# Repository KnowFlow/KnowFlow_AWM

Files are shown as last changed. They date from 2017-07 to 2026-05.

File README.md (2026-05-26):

This branch is for ongoing development

# KnowFlow - an open source river quality meter with Arduino

KnowFlow is an open source water monitoring device and an education program.



For the device part, KnowFlow is designed for environmental activists, researchers, students... anyone
who wants to know the water quality using low cost and customized tools. It is based on Arduino Uno and 
can currently monitor 5 parameters: Temperature, pH, ORP, Electrical conductivity and Dissolved Oxygen. 
The data is stored on a micro SD card and can be read directly on phone by bluetooth (except for Dissolved Oxygen). 
All the modules are easy to change or add. Most of the sensors used are from DFRobot and Atlas Scientific, 
the main 2 sensor suppliers for Arduino users.

### Supported Hardware Platforms
- **Arduino Uno** (primary platform)
- **Arduino Mega 2560**
- **Arduino M0**
- **ESP32** ✅ (see [ESP32 README](ArduinoESP32/README.md))



For the education program, KnowFlow is an 8 week online course and a learning group hosted on 
Greenseed Project platform. During the course, we cover the fundamentals of water quality, indicators of water quality, 
Arduino and monitoring systems and show you how to build your own monitoring system based on Arduino. In addition to 
the 5 included in the KnowFlow kits, you can add other environmental sensors, such as carbon dioxide, ozone, 
dust, light, temperature, or humidity sensors, then add GPS and a communication module to connect data from a distance. 
Step by step demos in the course walk you through the learning process.

This page is a collective information for KnowFlow, it can also be found on github, [Youku](http://v.youku.com/v_show/id_XMTYzNTA1NzU1Mg==.html?spm=a2hzp.8253876.0.0&f=27620513).
Will release this series video tutorial on youtube later soon!

## KnowFlow Hardware 

A complete list of components, measurements, drawings, and other specifications can be found [here](https://docs.google.com/spreadsheets/d/1rwVUIwqTOvZiKi_0vdBPrXMIw2YB-nsFnhaVy5seE-M).
DFRobot also offers a [KnowFlow starter kit.](https://www.dfrobot.com/product-1649.html)

#### Central Control Unit: 
* Arduino Uno (DFRobot Bluno in this case) and 
* Expansion Shield (DFRobot Expansion Shield V7.1 in this case)  
* real time clock circuit board
#### Water Sensors: 
* pH (pH probe and pH circuit board)
* EC (EC probe and EC circuit board)
* ORP (ORP probe and ORP circuit board)
* Temperature (temperature probe and temperature circuit board)
* Dissolved Oxygen (DO probe, BNC and circuit board)
#### Analog conversion:
* DFRobot Gravity: I2C ADS1115 16-Bit ADC Module (DFR0553)
  * I2C address: `0x48` by default, or `0x49` when the module address switch is changed
  * Input range: `0~VCC`
  * Default channel mapping in firmware: `A0=EC`, `A1=pH`, `A2=ORP`, `A3=AUX`
#### Data Storage:
* Micro-SD module
* Micro SD card
#### Fit and finish:
* Mounting plate
* Water proof box(200mm_150mm_75mm)
* Water proof bushing
#### Other parts: 
* Wires
* Bread board
* Bolts and nuts
* Screws
* Battery
* Double-sided adhesive
* Write on tape
* Basic hand tools
* Spiral cable wrap 

## Installing KnowFlow Firmware
KnowFlow is designed for beginners. You don't need to have experience with Arduino or software development. 
KnowFlow is packaged with supporting software libraries to make it easier for you to enable different sensor features 
for your application. Feel free to post your software questions on our wiki page on public lab or github.

### Firmware Versions

This repository contains multiple firmware versions for different hardware configurations:

#### 1. ArduinoUnoDo
- **Location**: `ArduinoUnoDo/WaterMonitor/`
- **DO Sensor**: Uses Serial port communication (Rx(0), Tx(1))
- **Best for**: Atlas Scientific DO sensor or similar serial-based DO sensors
- **Note**: DO sensor uses Serial port, which may conflict with USB debugging

#### 2. ArduinoUnoGravityDo
- **Location**: `ArduinoUnoGravityDo/WaterMonitorDo/`
- **DO Sensor**: Uses analog pin A0 (Gravity DO sensor)
- **Best for**: DFRobot Gravity DO sensor
- **Features**: Includes calibration support for pH and EC sensors
- **Recommended**: This is the most feature-complete version

#### 3. ArduinoESP32
- **Location**: `ArduinoESP32/WaterMonitorESP32/`
- **DO Sensor**: Uses analog pin GPIO33 (Gravity DO sensor)
- **Best for**: ESP32 development boards
- **Features**: 
  - Uses ESP32's 12-bit ADC for higher precision
  - Compatible with all 5 sensors
  - Ready for WiFi/IOT features (planned)
- **Note**: Requires ESP32 board support in Arduino IDE

#### 4. Firmware (Legacy)
- **Location**: `Firmware/WaterMonitor/WaterMonitor/`
- **Status**: Legacy version, contains compiled binaries
- **Note**: Use for reference only

### Installation Steps

1. **Download Arduino IDE** (version 1.8.2 or later)
   - Download link: https://www.arduino.cc/en/Main/Software

2. **Download KnowFlow code**
   ```bash
   git clone https://github.com/KnowFlow/KnowFlow_AWM.git
   ```

3. **Choose the appropriate firmware version**
   - For **ESP32**: Use `ArduinoESP32/WaterMonitorESP32/` (see [ESP32 README](ArduinoESP32/README.md))
   - For **Gravity DO sensor** (Arduino Uno): Use `ArduinoUnoGravityDo/WaterMonitorDo/`
   - For **Serial DO sensor** (Arduino Uno): Use `ArduinoUnoDo/WaterMonitor/`

4. **Install required libraries**
   - Copy libraries from `Firmware/libraries/` to your Arduino IDE libraries folder
   - Or install OneWire library via Library Manager: Sketch → Include Library → Manage Libraries → Search "OneWire"

5. **Configure your hardware**
   - Edit `config.h` (or `Config.h`) to match your sensor pins and calibration values
   - Enable/disable debug output by uncommenting `DEBUG_AVR` or `DEBUG_M0`

6. **Upload to board**
   - Open `WaterMonitor.ino` (or `WaterMonitorDo.ino`) in Arduino IDE
   - Connect your Arduino Uno board
   - Select Tools → Board: Arduino Uno
   - Select Tools → Port: (your USB port)
   - Click "Verify" then "Upload"

### DFR0553 ADC configuration

The enhanced `ArduinoUnoDo/WaterMonitor` firmware supports the Gravity DFR0553 I2C 16-bit ADC module without requiring the external DFRobot ADS1115 library. Configure it in `ArduinoUnoDo/WaterMonitor/config.h`:

* `ENABLE_DFR0553_ADC`: enable or disable the I2C ADC path.
* `DFR0553_I2C_ADDRESS`: default `0x48`; set to `0x49` if the hardware address switch is changed.
* `DFR0553_FULL_SCALE_MV`: default `6144.0f`, matching the ADS1115 `+/-6.144V` full-scale setting used for `0~VCC` single-ended sensor inputs.
* `DFR0553_EC_CHANNEL`, `DFR0553_PH_CHANNEL`, `DFR0553_ORP_CHANNEL`: map the EC, pH, and ORP analog front ends to ADS1115 channels.

If the DFR0553 is not detected on I2C, the firmware falls back to the original MCU `analogRead()` path for the analog sensors.

## FAQ

### Q: Why can't I verify the code?
**A:** The IDE may be missing a library, most often OneWire. 
Install the missing library from Sketch → Include Library → Manage Libraries. Search "OneWire" then install it.

### Q: Which firmware version should I use?
**A:** 
- Use **ArduinoUnoGravityDo** if you have DFRobot Gravity DO sensor (recommended)
- Use **ArduinoUnoDo** if you have Atlas Scientific or other serial-based DO sensors
- Check your DO sensor documentation to determine which type you have

### Q: How do I calibrate the sensors?
**A:** 
- Edit `config.h` (or `Config.h`) in your firmware directory
- Set `PHOFFSET` for pH calibration offset
- Set `ECKVALUE` for EC sensor K value
- Re-upload the firmware after calibration

### Q: Can I use both Serial DO and Gravity DO?
**A:** No, you need to choose one firmware version based on your hardware. The two versions are incompatible due to different DO sensor interfaces.

### Q: How do I enable debug output?
**A:** 
- Open `config.h` (or `Config.h`)
- Uncomment `#define DEBUG_AVR` for Arduino Uno/Mega
- Or uncomment `#define DEBUG_M0` for Arduino M0
- Re-upload the firmware

## How to build KnowFlow 
Instructions are available [here.](https://publiclab.org/notes/shanlter/06-08-2017/knowflow-automatic-water-meter)

## How to contribute:
See this [tutorial.](https://help.github.com/articles/creating-a-pull-request/)
1. Fork the repository!
1. Create your feature branch: git checkout -b my-new-feature
1. Commit your changes: git commit -am 'Add some feature'
1. Push to the branch: git push origin my-new-feature
1. Submit a pull request
 
## About Branches
**master** is the current stable release.

**development** is the research version. It has experimental features that are not fully tested. For example, IOT
integrations, new sensors, etc.

**test** is for the team to practice with github. We will delete when we figure out how to use github. (We are newbees
to github, so please forgive any stupid errors. Suggestions are welcome!) :)

## To DO List
- [x] Support DO Sensor from DFRobot
- [x] Modify the construction of the files system
- [x] Code cleanup and configuration unification
- [x] Add DFR0553 I2C 16-bit ADC support for ArduinoUnoDo analog sensors
- [ ] Add YouTube video tutorial
- [ ] Website setup (www.knowflow.org)
- [x] IOT feature for enhanced ArduinoUnoDo firmware
- [x] Calibration function (partially implemented in ArduinoUnoGravityDo)
- [x] ESP32 support (basic sensor functionality)
- [ ] ESP32 WiFi/IOT features
- [x] Low power function for enhanced ArduinoUnoDo firmware

## Contact

Email addresses for the KnowFlow team.

* Rockets <Rockets.xia@dfrobot.com>
* He Shan  <shanh0510@gmail.com>
* Lauren <Lauren.pan@hotmail.com>
* Jason <jason.liang@dfrobot.com>

## Documents

 * [Tutorial][1]
 * [GreenSeed online courses][2]
 * [Application:非洲茶园水质调研][3]
 * [Application:Willow Creek Water Quality Monitoring][4]
 * [KnowFlow Special Design][6]

## License

All KnowFlow related materials are released under the [Attribution-NonCommercial-ShareAlike 4.0 International (CC BY-NC-SA 4.0)][5]

## This project has benefited from the support from the following funders:

* GreenSeed Foundation
* Mushroom Cloud Maker Space

  [1]: https://publiclab.org/notes/shanlter/06-08-2017/knowflow-automatic-water-meter
  [2]: http://blog.sina.com.cn/s/blog_9f86b6d50102w9m1.html
  [3]: http://www.dfrobot.com.cn/community/thread-26733-1-1.html
  [4]: https://publiclab.org/notes/MadTinker/07-31-2017/willow-creek-water-quality-monitoring
  [5]: https://creativecommons.org/licenses/by-nc-sa/4.0/
  [6]:https://www.instructables.com/id/KnowFlow-Special-Design/

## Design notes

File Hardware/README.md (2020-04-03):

## Diagrams
Box_and_Plate diagrams are provided by KnowFlow team.
Box_and_Plate_v2 is update.
It's have more posion to put the board and easy to install.

Knowflow board diagrams are provided by a community member. These diagrams were created in 
[Sketchup](https://www.sketchup.com/) and can be edited with free software. They offer an alternative mounting
layout for [this box.](http://cgi.ebay.com/ws/eBayISAPI.dll?ViewItemVersion&item=112434164913&view=all&tid=1783224276001)
Drawings will print 1:1 so the printout can be used as a template to drill holes. Consider 
[this item](https://www.dollartree.com/Home-Collection-Paddle-Cutting-Boards/p338120/index.pro) 
as a mounting plate.

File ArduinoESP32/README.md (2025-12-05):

# KnowFlow ESP32 版本

这是 KnowFlow 水质监测系统的 ESP32 移植版本，支持 ESP32 开发板运行原有的 5 个传感器（pH, Temperature, DO, EC, ORP）。

## 特性

- ✅ 支持所有 5 个传感器（pH, Temperature, DO, EC, ORP）
- ✅ 利用 ESP32 的 12-bit ADC 获得更高精度
- ✅ 兼容现有的传感器驱动代码
- ✅ 支持 SD 卡数据存储
- ✅ 支持 RTC 时间记录
- 🔜 WiFi 数据上传（计划中）
- 🔜 蓝牙配置（计划中）

## 硬件要求

### 开发板
- ESP32 开发板（推荐 ESP32-DevKitC）
- 支持 Arduino IDE 的 ESP32 开发环境

### 传感器
- pH 传感器（DFRobot Gravity pH Sensor）
- EC 传感器（DFRobot Gravity EC Sensor）
- ORP 传感器（DFRobot Gravity ORP Sensor）
- DO 传感器（DFRobot Gravity DO Sensor）
- 温度传感器（DS18B20）

### 其他
- Micro SD 卡模块（SPI 接口）
- RTC 模块（I2C 接口，可选，可使用 NTP）

## 引脚配置

### 传感器引脚（ESP32 GPIO）
- **pH**: GPIO34 (ADC1_CH6)
- **EC**: GPIO35 (ADC1_CH7)
- **ORP**: GPIO32 (ADC1_CH4)
- **DO**: GPIO33 (ADC1_CH5)
- **Temperature**: GPIO4 (OneWire)

### SD 卡引脚（SPI）
- **MOSI**: GPIO23
- **MISO**: GPIO19
- **CLK**: GPIO18
- **CS**: GPIO5

### I2C 引脚（RTC）
- **SDA**: GPIO21
- **SCL**: GPIO22

## 安装步骤

### 1. 安装 Arduino IDE 和 ESP32 支持

1. 下载并安装 [Arduino IDE](https://www.arduino.cc/en/software)（1.8.13 或更高版本）

2. 添加 ESP32 开发板支持：
   - 打开 Arduino IDE
   - 文件 → 首选项
   - 在"附加开发板管理器网址"中添加：
     ```
     https://raw.githubusercontent.com/espressif/arduino-esp32/gh-pages/package_esp32_index.json
     ```
   - 工具 → 开发板 → 开发板管理器
   - 搜索 "ESP32" 并安装

### 2. 安装必要的库

从 `Firmware/libraries/` 目录复制以下库到 Arduino IDE 的 libraries 文件夹：
- OneWire
- Wire（ESP32 已内置，但可能需要）

或者通过库管理器安装：
- OneWire（搜索 "OneWire"）

### 3. 配置项目

1. 打开 `WaterMonitorESP32.ino`
2. 编辑 `Config.h` 调整以下配置：
   - 传感器校准值（`PHOFFSET`, `ECKVALUE`）
   - 调试输出（`DEBUG_ESP32`）
   - 引脚配置（如果需要修改）

### 4. 上传代码

1. 连接 ESP32 开发板到电脑
2. 选择开发板：工具 → 开发板 → ESP32 Arduino → ESP32 Dev Module
3. 选择端口：工具 → 端口 → （你的 ESP32 端口）
4. 点击"上传"

## ADC 精度说明

ESP32 使用 12-bit ADC（0-4095），比 Arduino 的 10-bit ADC（0-1023）精度更高。代码中包含了适配层，可以将 ESP32 的 ADC 值转换为 Arduino 兼容的值，同时也可以直接使用 ESP32 的更高精度。

### 使用 Arduino 兼容模式（默认）
传感器驱动会自动将 ESP32 的 12-bit 值转换为 10-bit 值，保持与 Arduino 版本的兼容性。

### 使用 ESP32 高精度模式
如果需要更高的精度，可以修改传感器驱动代码，直接使用 ESP32 的 12-bit ADC 值。

## 电压兼容性

### 传感器输出
- DFRobot Gravity 传感器通常输出 0-3.3V 信号，兼容 ESP32 的 3.3V 逻辑电平
- 传感器模块可能需要 5V 供电，但输出信号是 3.3V 兼容的

### 注意事项
- 如果传感器需要 5V 供电，确保 ESP32 开发板有 5V 输出引脚，或使用外部 5V 电源
- 不要将 5V 信号直接连接到 ESP32 GPIO（会损坏芯片）
- 如果传感器输出超过 3.3V，需要使用电平转换电路

## 故障排除

### 问题：编译错误
- 确保已安装 ESP32 开发板支持
- 确保所有必要的库都已安装
- 检查 Arduino IDE 版本（需要 1.8.13+）

### 问题：传感器读数不准确
- 检查引脚配置是否正确
- 检查传感器供电是否正常
- 检查 ADC 配置（`initESP32ADC()` 函数）
- 可能需要重新校准传感器

### 问题：SD 卡无法识别
- 检查 SPI 引脚连接
- 检查 SD 卡格式（建议使用 FAT32）
- 检查 CS 引脚配置

## 未来计划

- [ ] WiFi 数据上传功能
- [ ] 蓝牙配置功能
- [ ] NTP 时间同步
- [ ] OTA 固件更新
- [ ] Web 配置界面
- [ ] 低功耗模式

## 贡献

欢迎提交 Issue 和 Pull Request！

## 许可证

与主项目相同：GNU General Public License v3.0

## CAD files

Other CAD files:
Hardware/Box_and_Plate_v2.dwg
Hardware/Box_and_Plate.dwg

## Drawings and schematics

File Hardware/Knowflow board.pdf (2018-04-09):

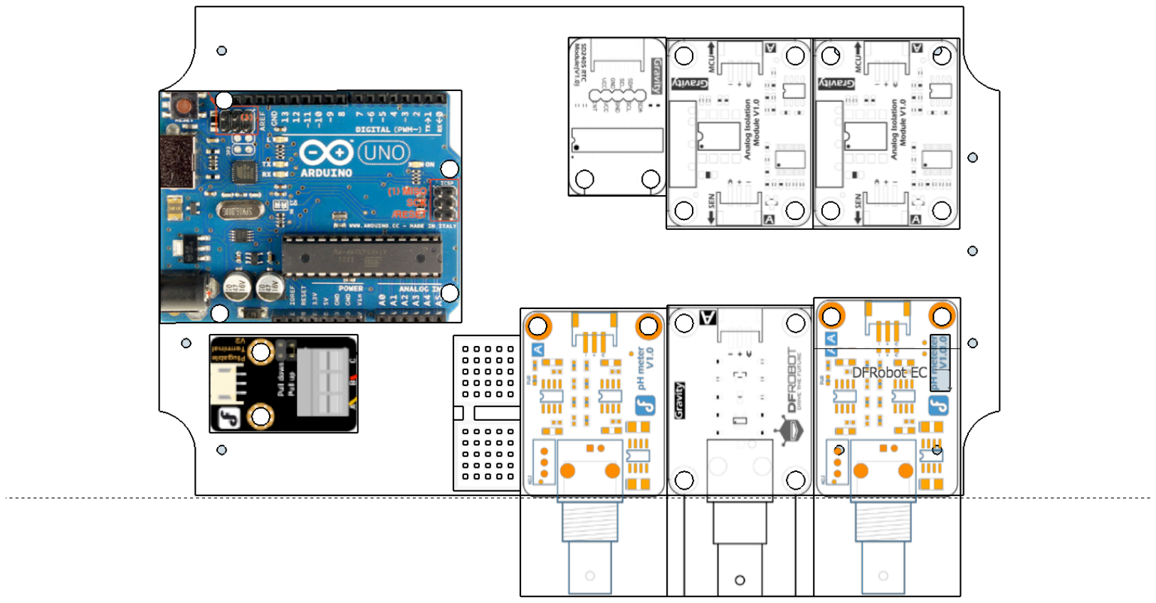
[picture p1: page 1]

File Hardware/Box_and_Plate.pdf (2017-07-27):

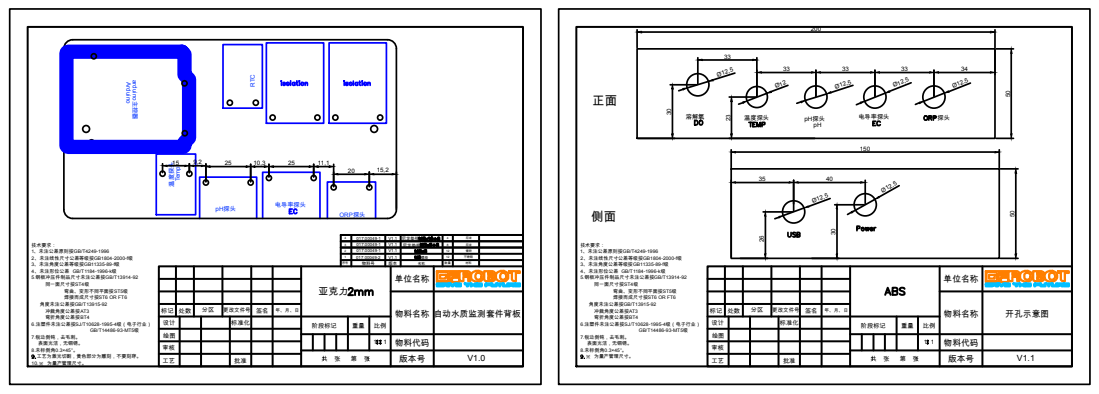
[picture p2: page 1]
4、未注形位公差 GB/T1184-1996-k级; 焊接而成尺寸按ST6 OR FT6; ※ 为量产管理尺寸。; 10.※ 为量产管理尺寸。

4 017.00049-1 | V1.1 | 尼龙垫柱 | 4 尼龙
3 017.00049-1 2/1 017.00049-1 | V1.1 | 尼龙垫柱 | 8 尼龙 12 镀锌

017.00049-2 | V1.1 | 螺母 | 12 不锈钢

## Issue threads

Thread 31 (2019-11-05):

We will have a NB-IoT version of KnowFlow

rockets-cn, 2019-11-05:
We are going to rebuild KnowFlow base on a new board that is using the NB-IoT system.
hope that we can release demo in a few weeks.

thegspdman, 2020-03-22:
Hi there;
I bought the knowFlow kit from DFrobot for a project for my thesis and now I am trying to verify/upload the code to the Bluno but i am having all sorts of fault messages. I am not god with coding, unfortunately my field is water and wastewater. Would you be kind enough and email me a working code or put me towards the right direction please. IoT project sounds brilliant.
Kind regards
Zak

rockets-cn, 2020-03-25:
How can I help?

thegspdman, 2020-03-25:
Hi there;
Very happy to hear from you.
I am a environment and water/wastewater student.I bought a water monitoring
kit " excluding ORP sensor" from DFrobot, but I am having problems with the
program/equipment.
1- The Bluno can't be detected by my Dell XPS with windows 10
2- I got all kind of errors verifying the program, like program is too big,
stray errors ...and so forth.
3- I have a Mega from Keyestudio that can be recognized by my PC, I could
verify but unfortunately it doesn't upload to board.
I would love to use the Bluno and the rest of the kit if it only works.
Can you help please, I am trying to do it as a project for my thesis to
raise awareness about IOT to be introduced for water and wastewater
treatment plants.
Kind regards
Ishak

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

--
Ishak Fernini
Tåsjö 230
Hoting -Jämtland-
Sverige
Tel: +44 72 532 0631
thegspdman@gmail.com

rockets-cn, 2020-04-03:
I think maybe you have to install the driver for the Bluno.
maybe we can use zoom or another way contact directly.

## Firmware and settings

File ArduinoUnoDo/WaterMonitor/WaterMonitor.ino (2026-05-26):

/*********************************************************************
 * WaterMonitor.ino - Enhanced KnowFlow with IoT, Calibration, and Power Management
 *
 * Copyright (C)    2024   KnowFlow Team
 * Enhanced version with WiFi/IoT connectivity, calibration, and power management
 *
 * Description:
 * Enhanced water quality monitoring system with:
 * - WiFi/IoT connectivity via MQTT
 * - Automatic sensor calibration
 * - Power management with sleep modes
 * - Battery monitoring and solar charging support
 * - Real-time data transmission
 *
 * Hardware platform   : Arduino Uno with WiFi shield or ESP32
 * New features added  : IoT connectivity, calibration, power management
 * version :  V2.0
 * date    :  2024-07-21
 **********************************************************************/

#include <SPI.h>
#include <SD.h>
#include <Wire.h>
#include <EEPROM.h>
#include "config.h"

// Core modules
#include "GravitySensorHub.h"
#include "GravityRtc.h"
#include "SdService.h"
#include "Debug.h"

// New enhanced features
#include "IoTService.h"
#include "CalibrationService.h"
#include "PowerManager.h"

// Clock module
GravityRtc rtc;

// Sensor monitoring
GravitySensorHub sensorHub;
SdService sdService = SdService(sensorHub.sensors);

// New services
IoTService iotService;
CalibrationService calibrationService(&sensorHub, &sdService);
PowerManager powerManager;

// System state
unsigned long lastUpdateTime = 0;
unsigned long updateInterval = 5000; // 5 seconds between readings
bool systemInitialized = false;

void setup() {
    Serial.begin(DEBUG_BAUD_RATE);
    Serial.println(F("KnowFlow Enhanced Water Monitor v2.0"));
    Serial.println(F("====================================="));

    // Initialize EEPROM for calibration data
    EEPROM.begin(512);

    // Initialize RTC
    rtc.setup();

    // Initialize sensor hub
    sensorHub.setup();

    // Initialize SD service
    sdService.setup();

    // Initialize calibration service
    calibrationService.setup();

    // Initialize power manager
    PowerConfig powerConfig;
    powerConfig.sleepInterval = POWER_SLEEP_INTERVAL;
    powerConfig.lowBatteryThreshold = LOW_BATTERY_THRESHOLD;
    powerConfig.criticalBatteryThreshold = CRITICAL_BATTERY_THRESHOLD;
    powerConfig.enableBatteryMonitoring = ENABLE_BATTERY_MONITORING;
    powerConfig.enableSensorPowerControl = ENABLE_SENSOR_POWER_CONTROL;
    powerConfig.enableSolarCharging = ENABLE_SOLAR_CHARGING;

    powerManager.setup(powerConfig);

    // Initialize IoT service (WiFi/MQTT)
    Serial.print(F("Initializing IoT service..."));
    iotService.setup(WIFI_SSID, WIFI_PASSWORD, MQTT_SERVER, MQTT_PORT);
    Serial.println(F("OK"));

    systemInitialized = true;
    Serial.println(F("System initialization complete!"));
    Serial.println(F("====================================="));
}

void loop() {
    if (!systemInitialized) return;

    unsigned long currentTime = millis();

    // Update all services
    rtc.update();
    sensorHub.update();
    sdService.update();
    calibrationService.loop();
    powerManager.loop();
    iotService.loop();

    // Main update cycle
    if (currentTime - lastUpdateTime > updateInterval) {
        lastUpdateTime = currentTime;

        // Get all sensor readings
        float ph = sensorHub.getValueBySensorNumber(0);
        float temp = sensorHub.getValueBySensorNumber(1);
        float doValue = sensorHub.getValueBySensorNumber(2);
        float ec = sensorHub.getValueBySensorNumber(3);
        float orp = sensorHub.getValueBySensorNumber(4);

        // Print readings
        printSensorReadings(ph, temp, doValue, ec, orp);

        // Publish to IoT
        if (iotService.isConnected()) {
            iotService.publishData(ph, temp, doValue, ec, orp);
        }

        // Check for calibration commands
        handleSerialCommands();
    }
}

void printSensorReadings(float ph, float temp, float doValue, float ec, float orp) {
    Serial.println(F("=== Current Readings ==="));
    Serial.print(F("pH:        "));
    Serial.println(ph, 2);
    Serial.print(F("Temperature: "));
    Serial.println(temp, 2);
    Serial.print(F("DO:        "));
    Serial.println(doValue, 2);
    Serial.print(F("EC:        "));
    Serial.println(ec, 2);
    Serial.print(F("ORP:       "));
    Serial.println(orp, 2);

    // Print battery status
    Serial.print(F("Battery:   "));
    Serial.print(powerManager.getBatteryVoltage(), 2);
    Serial.print(F("V ("));
    Serial.print(powerManager.getBatteryPercentage());
    Serial.println(F("%)"));

    Serial.print(F("WiFi:      "));
    Serial.println(iotService.isConnected() ? F("Connected") : F("Disconnected"));
    Serial.println(F("========================"));
}

void handleSerialCommands() {
    if (Serial.available()) {
        String command = Serial.readStringUntil('\n');
        command.trim();

        if (command == "calibrate_ph") {
            Serial.println(F("Starting pH calibration..."));
            calibrationService.startCalibration(CALIBRATION_PH_3POINT);
        } else if (command == "calibrate_ec") {
            Serial.println(F("Starting EC calibration..."));
            calibrationService.startCalibration(CALIBRATION_EC_1POINT);
        } else if (command == "calibrate_do") {
            Serial.println(F("Starting DO calibration..."));
            calibrationService.startCalibration(CALIBRATION_DO_2POINT);
        } else if (command == "calibrate_orp") {
            Serial.println(F("Starting ORP calibration..."));
            calibrationService.startCalibration(CALIBRATION_ORP_1POINT);
        } else if (command == "sleep") {
            Serial.println(F("Entering sleep mode..."));
            powerManager.enterSleepMode();
        } else if (command == "deep_sleep") {
            Serial.println(F("Entering deep sleep mode..."));
            powerManager.enterDeepSleepMode();
        } else if (command == "battery") {
            Serial.print(F("Battery: "));
            Serial.print(powerManager.getBatteryVoltage());
            Serial.print(F("V ("));
            Serial.print(powerManager.getBatteryPercentage());
            Serial.println(F("%)"));
        } else if (command == "help") {
            printHelp();
        }
    }
}

void printHelp() {
    Serial.println(F("KnowFlow Enhanced Commands:"));
    Serial.println(F("  calibrate_ph   - Start pH 3-point calibration"));
    Serial.println(F("  calibrate_ec   - Start EC 1-point calibration"));
    Serial.println(F("  calibrate_do   - Start DO 2-point calibration"));
    Serial.println(F("  calibrate_orp  - Start ORP 1-point calibration"));
    Serial.println(F("  sleep          - Enter sleep mode"));
    Serial.println(F("  deep_sleep     - Enter deep sleep mode"));
    Serial.println(F("  battery        - Show battery status"));
    Serial.println(F("  help           - Show this help"));
}

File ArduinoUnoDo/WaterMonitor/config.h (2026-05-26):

#pragma once

// Serial print switch
// Uncomment one of the following to enable debug output
//#define DEBUG_AVR  // For Arduino Uno, Mega2560
//#define DEBUG_M0   // For Arduino M0

// WiFi Configuration
#define WIFI_SSID "YourWiFiNetwork"
#define WIFI_PASSWORD "YourWiFiPassword"
#define MQTT_SERVER "your.mqtt.server.com"
#define MQTT_PORT 1883
#define MQTT_TOPIC "knowflow/data"
#define MQTT_CLIENT_ID "KnowFlowDevice"

// Power Management Configuration
#define POWER_SLEEP_INTERVAL 60000  // milliseconds (1 minute)
#define LOW_BATTERY_THRESHOLD 3.3   // Volts
#define CRITICAL_BATTERY_THRESHOLD 3.0  // Volts
#define ENABLE_BATTERY_MONITORING true
#define ENABLE_SENSOR_POWER_CONTROL true
#define ENABLE_SOLAR_CHARGING false

// Calibration Configuration
#define CALIBRATION_EEPROM_ADDR 0
#define ENABLE_AUTO_CALIBRATION true
#define CALIBRATION_STABILITY_TIME 10000  // milliseconds
#define PHOFFSET 0.0  // pH calibration offset
#define ECKVALUE 1.0  // EC K value for calibration

// The maximum length of the sensor filter array
#define ARRAYLENGTH 10

// SD card update data time, 60,000 is 1 minute
#define SDUPDATEDATATIME 60000

// EC sensor is selected by default, comment this line to use TDS sensor
#define SELECTEC

// Sensor pin settings
// DO sensor uses Serial port Rx(0), Tx(1) for ArduinoUnoDo version
#if defined(ARDUINO_ARCH_ESP32)
#define ECPIN 34
#define PHPIN 35
#define ORPPIN 32
#define DOPIN 33
#define BATTERY_MONITOR_PIN 36
#else
#define DOPIN A0  // Not used in this version (DO uses Serial)
#define ECPIN A1
#define PHPIN A2
#define ORPPIN A3
#define BATTERY_MONITOR_PIN A7
#endif
#define TDSPIN ECPIN
#define TEMPPIN 5
#define RTC_SDA A4
#define RTC_SCL A5

// Compatibility aliases used by the enhanced WaterMonitor services.
#define EC_PIN ECPIN
#define PH_PIN PHPIN
#define ORP_PIN ORPPIN
#define DO_PIN DOPIN
#define TEMP_PIN TEMPPIN

// DFRobot Gravity DFR0553 I2C ADS1115 16-bit ADC
#define ENABLE_DFR0553_ADC true
#define DFR0553_I2C_ADDRESS 0x48
#define DFR0553_FULL_SCALE_MV 6144.0f
#define DFR0553_EC_CHANNEL 0
#define DFR0553_PH_CHANNEL 1
#define DFR0553_ORP_CHANNEL 2
#define DFR0553_AUX_CHANNEL 3

// Power Control Pins
#define SENSOR_POWER_PIN 8
#define SOLAR_CHARGE_PIN 9

// SD Card Configuration
#define SD_CS_PIN 4
#define ENABLE_SD_LOGGING true

// Debug Configuration
#define ENABLE_DEBUG true
#define DEBUG_BAUD_RATE 9600

// The maximum number of sensors
#define SENSORCOUNT 5

// The sensor corresponds to the array number
// ph=0, temperature=1..., the maximum number is SENSORCOUNT-1
enum SensorNumber
{
	phSensor = 0,
	temperatureSensor,
	doSensor,
	ecSensor,
	tdsSensor = 3,
	orpSensor
};

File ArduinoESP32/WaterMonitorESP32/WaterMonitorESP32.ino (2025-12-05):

/*********************************************************************
* WaterMonitorESP32.ino
*
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
* Description:
* This sample code is mainly used to monitor water quality on ESP32
* including ph, temperature, dissolved oxygen, ec and orp,etc.
*
* Software Environment: Arduino IDE 1.8.13+ with ESP32 board support
* ESP32 Board Manager URL: https://raw.githubusercontent.com/espressif/arduino-esp32/gh-pages/package_esp32_index.json
*
* Hardware platform: ESP32 (ESP32-DevKitC recommended)
* Sensor pin:
* EC  : GPIO35 (ADC1_CH7)
* PH  : GPIO34 (ADC1_CH6)
* ORP : GPIO32 (ADC1_CH4)
* RTC : I2C (GPIO21 SDA, GPIO22 SCL)
* DO  : GPIO33 (ADC1_CH5)
* Temperature: GPIO4 (OneWire)
*
* SD card attached to SPI bus as follows:
* ESP32:  MOSI - GPIO23, MISO - GPIO19, CLK - GPIO18, CS - GPIO5
*
* author  :  KnowFlow Team
* version :  V1.0
* date    :  2024
**********************************************************************/

#include <SPI.h>
#include <SD.h>
#include <Wire.h>
#include "GravitySensorHub.h"
#include "GravityRtc.h"
#include "GravityEc.h"
#include "GravityPh.h"
#include "GravityDo.h"
#include "OneWire.h"
#include "SdService.h"
#include "Debug.h"
#include "Config.h"

// Alias clock module logic as rtc
GravityRtc rtc;

// Alias sensor logic as sensorHub 
GravitySensorHub sensorHub;

// Alias SD logic as sdService applied to sensors
SdService sdService = SdService(sensorHub.sensors);

void setup() {
	// Open communication at 115200 baud (ESP32 default)
	Serial.begin(115200);
	delay(1000);  // Give serial monitor time to connect
	
	// Initialize ESP32 ADC
	initESP32ADC();
	
	Debug::println("=== KnowFlow ESP32 Water Monitor ===");
	Debug::println("Serial begin");
	
	// Initialize RTC module
	Debug::println("rtc.setup");
	rtc.setup();

	// Reset and initialize sensors
	Debug::println("sensorHub setup");
	sensorHub.setup();

	// Apply calibration offsets
	// Calibrate pH
	((GravityPh*)(sensorHub.sensors[phSensor]))->setOffset(PHOFFSET);
	Debug::print("pH offset: ");
	Debug::println(PHOFFSET);
	
	// Calibrate EC if present
	#ifdef SELECTEC
	((GravityEc*)(sensorHub.sensors[ecSensor]))->setKValue(ECKVALUE);
	Debug::print("EC K Value: ");
	Debug::println(ECKVALUE);
	#endif
	
	// Check for SD card and configure datafile
	Debug::println("sdService setup");
	sdService.setup();
	
	Debug::println("Setup complete!");
}

// Create variable to track time
unsigned long updateTime = 0;

void loop() {
	// Update time from clock module
	rtc.update();

	// Collect sensor readings
	sensorHub.update();

	// Write data to SD card
	sdService.update();
	
	// Optional: Serial output for debugging (every 2 seconds)
	#ifdef DEBUG_ESP32
	if(millis() - updateTime > 2000)
	{
		updateTime = millis();
		Serial.print(F("pH= "));
		Serial.print(sensorHub.getValueBySensorNumber(phSensor));
		Serial.print(F("  Temp= "));
		Serial.print(sensorHub.getValueBySensorNumber(temperatureSensor));
		Serial.print(F("  DO= "));
		Serial.print(sensorHub.getValueBySensorNumber(doSensor));
		Serial.print(F("  EC= "));
		Serial.print(sensorHub.getValueBySensorNumber(ecSensor));
		Serial.print(F("  ORP= "));
		Serial.println(sensorHub.getValueBySensorNumber(orpSensor));
	}
	#endif
}

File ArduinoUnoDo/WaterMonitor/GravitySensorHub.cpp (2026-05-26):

/*********************************************************************************************
* GravitySensorHub.cpp
*
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
* Description:
*
* author  :  Jason(jason.ling@dfrobot.com)
* version :  V1.0
* date    :  2017-04-12
*********************************************************************************************/


#include "GravitySensorHub.h"
#include "GravityPh.h"
#include "GravityOrp.h"
#include "GravityEc.h"
#include "GravityTemperature.h"
#include "SensorDo.h"
#include "config.h"

//********************************************************************************************
// function name: sensors []
// Function Description: Store the array of sensors
// Parameters: 0 ph sensor
// Parameters: 1 temperature sensor
// Parameters: 2 Dissolved oxygen sensor
// Parameters: 3 Conductivity sensor
// Parameters: 4 Redox potential sensor
//********************************************************************************************

GravitySensorHub::GravitySensorHub()
{
	for (size_t i = 0; i < this->SensorCount; i++)
	{
		this->sensors[i] = NULL;
	}

	this->sensors[phSensor] = new GravityPh(&this->adc, DFR0553_PH_CHANNEL);
	this->sensors[temperatureSensor] = new GravityTemperature(TEMPPIN);
	this->sensors[doSensor] = new SensorDo();
	#ifdef SELECTEC
		this->sensors[ecSensor] = new GravityEc(this->sensors[temperatureSensor], &this->adc, DFR0553_EC_CHANNEL);
	#else
		// Note: ArduinoUnoDo version uses GravityEc for both EC and TDS
		this->sensors[ecSensor] = new GravityEc(this->sensors[temperatureSensor], &this->adc, DFR0553_EC_CHANNEL);
	#endif
	this->sensors[orpSensor] = new GravityOrp(&this->adc, DFR0553_ORP_CHANNEL);

}

//********************************************************************************************
// function name: ~ GravitySensorHub ()
// Function Description: Destructor, frees all sensors
//********************************************************************************************
GravitySensorHub::~GravitySensorHub()
{
	for (size_t i = 0; i < SensorCount; i++)
	{
		if (this->sensors[i])
		{
			delete this->sensors[i];
		}
	}
}


//********************************************************************************************
// function name: setup ()
// Function Description: Initializes all sensors
//********************************************************************************************
void GravitySensorHub::setup()
{
#if ENABLE_DFR0553_ADC
	this->adc.setup(DFR0553_I2C_ADDRESS, DFR0553_FULL_SCALE_MV);
#endif

	for (size_t i = 0; i < SensorCount; i++)
	{
		if (this->sensors[i])
		{
			this->sensors[i]->setup();
		}
	}
}


//********************************************************************************************
// function name: update ()
// Function Description: Updates all sensor values
//********************************************************************************************
void GravitySensorHub::update()
{
	for (size_t i = 0; i < SensorCount; i++)
	{
		if (this->sensors[i])
		{
			this->sensors[i]->update();
		}
	}
}

//********************************************************************************************
// function name: getValueBySensorNumber ()
// Function Description: Get the sensor data
// Parameters: 0 ph sensor
// Parameters: 1 temperature sensor
// Parameters: 2 Dissolved oxygen sensor
// Parameters: 3 Conductivity sensor
// Parameters: 4 Redox potential sensor
// Return Value: Returns the acquired sensor data
//********************************************************************************************
double GravitySensorHub::getValueBySensorNumber(int num)
{
	if (num >= SensorCount)
	{
		return 0;
	}
	return this->sensors[num]->getValue();
}

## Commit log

2017-07-11 New drawing 20170711
    [Box_and_Plate.dwg]
2017-08-19 Update GravitySensorHub.cpp
    modify
    //this->sensors[0] = new GravityPh();
    to
    this->sensors[0] = new GravityPh();
2017-10-06 fixed spacing and code typos
    [GravityRtc.cpp, WaterMonitor.ino]
2017-10-15 file structure change
    [Box_and_Plate.dwg]
2017-10-25 Add GravityDo Sensor
2017-10-25 Update README.md
    add DFRobot Gravity DO sensor.
2017-12-14 Add Do sensor code
2017-12-29 添加TDS传感器代码
2018-01-19 modify GravityDo Temperature var
2018-04-15 added comments and bugfixes
    adding comments
    more comments
    [Config.h, GravityOrp.cpp, GravityRtc.cpp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]
2020-04-03 update the plate design
    design by Always Fu
    [Box_and_Plate_v2.dwg]
2025-12-05 Code cleanup, configuration unification, and ESP32 support
    - Code cleanup: Removed commented debug code, unified code style
    - Configuration unification: Created complete config.h for ArduinoUnoDo
    - Unified codebase: Use Config.h and enums consistently across versions
    - Updated README: Added version descriptions, installation guide, and FAQ
    - ESP32 support: Added basic ESP32 firmware version with sensor drivers
    - Created ESP32 project structure
    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
2026-05-26 Support DFR0553 ADC water monitor readings
    Add a local ADS1115/DFR0553 I2C ADC driver and wire pH, EC, and ORP readings through it with analogRead fallback. Keep the enhanced WaterMonitor services in the same commit because the sketch referen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
    Constraint: DFR0553 support must not add a new external ADS1115 dependency
    Rejected: Depend on the DFRobot ADS1115 library | a compact local driver keeps Arduino setup simpler
    Confidence: high
    Scope-risk: moderate
    Directive: Keep DFR0553 channel mapping centralized in ArduinoUnoDo/WaterMonitor/config.h
    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

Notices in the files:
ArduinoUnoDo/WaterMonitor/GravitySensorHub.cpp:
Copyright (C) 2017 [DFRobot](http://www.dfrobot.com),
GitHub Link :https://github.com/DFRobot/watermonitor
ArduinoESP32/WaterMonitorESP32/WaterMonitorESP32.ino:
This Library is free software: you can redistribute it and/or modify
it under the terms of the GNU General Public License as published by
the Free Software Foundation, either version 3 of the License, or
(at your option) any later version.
